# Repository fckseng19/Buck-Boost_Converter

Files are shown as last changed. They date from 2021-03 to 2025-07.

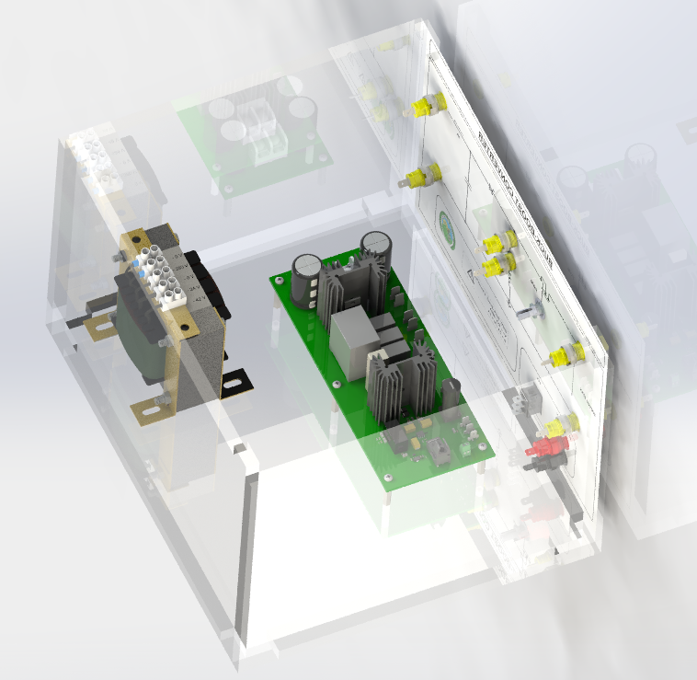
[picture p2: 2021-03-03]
Buck-Boost Module/atras_buck_boost.PNG

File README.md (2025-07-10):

# Buck-Boost_Converter
Aquí se encuentran todas las simulaciones utilizadas en el diseño del convertidor Buck-Boost como también los archivos de las PCB,Gerber, Drill, Assambly, schematics, BOM, etc

Modulos:





PCB:




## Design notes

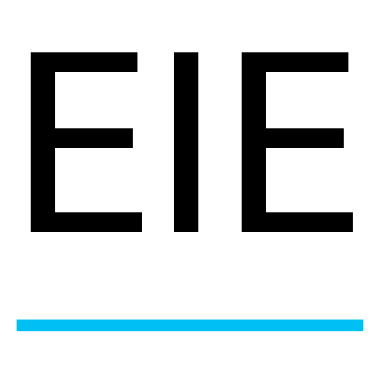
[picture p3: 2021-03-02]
Buck-Boost/PCB/Image/eie.png

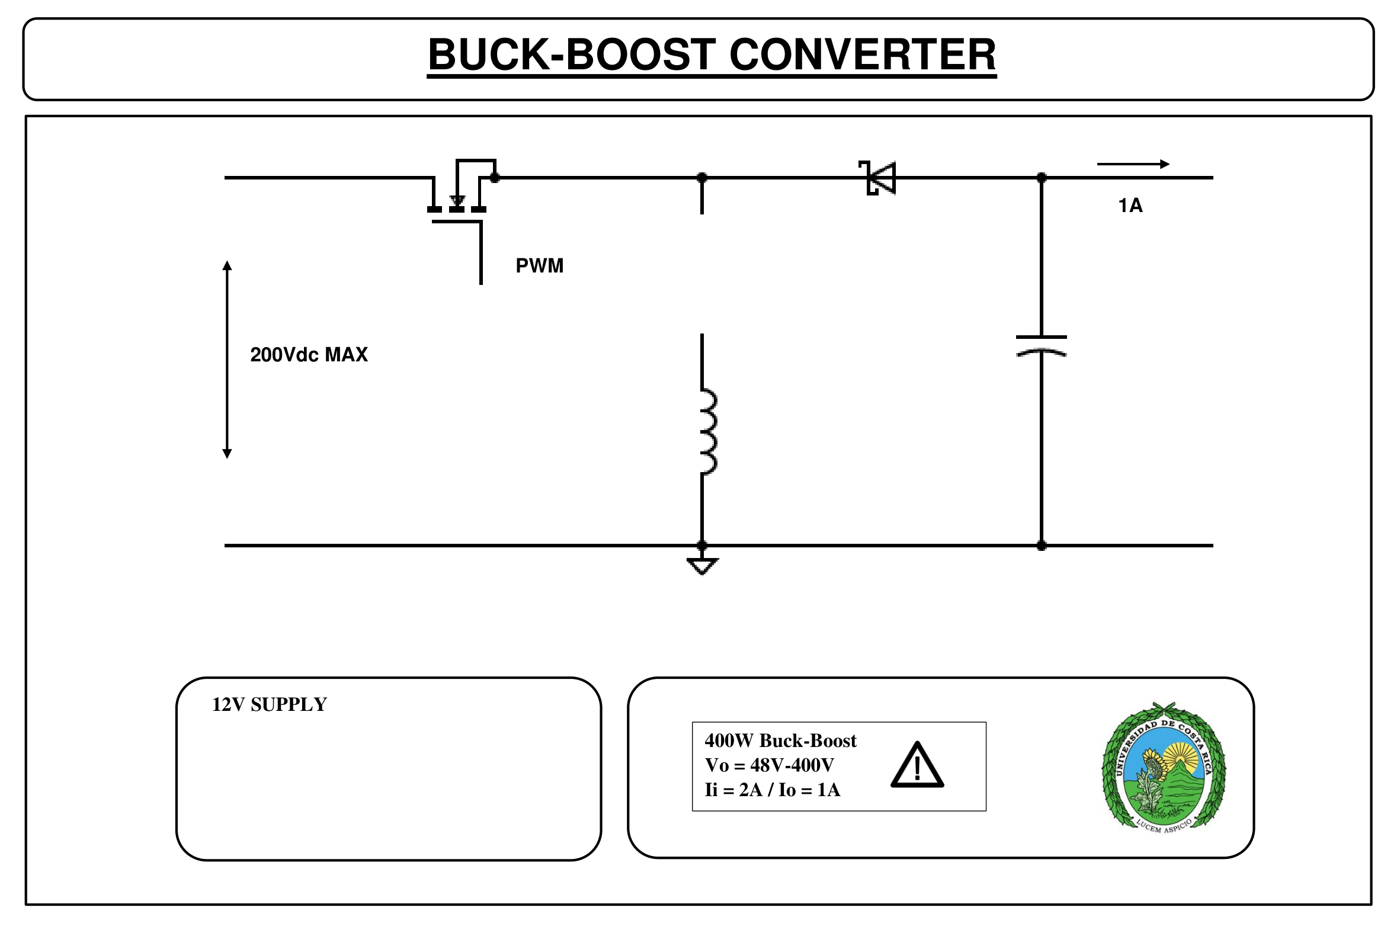
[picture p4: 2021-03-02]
Buck-Boost/Módulo/PANEL_FRONTAL_BUCKBOOST.png

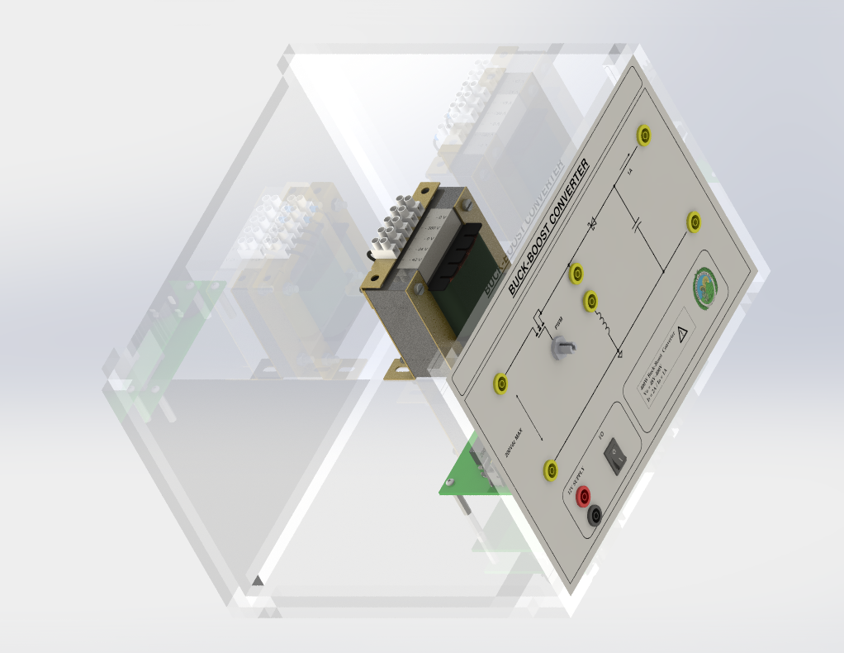
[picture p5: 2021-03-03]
Buck-Boost Module/lateral_buckboot.PNG

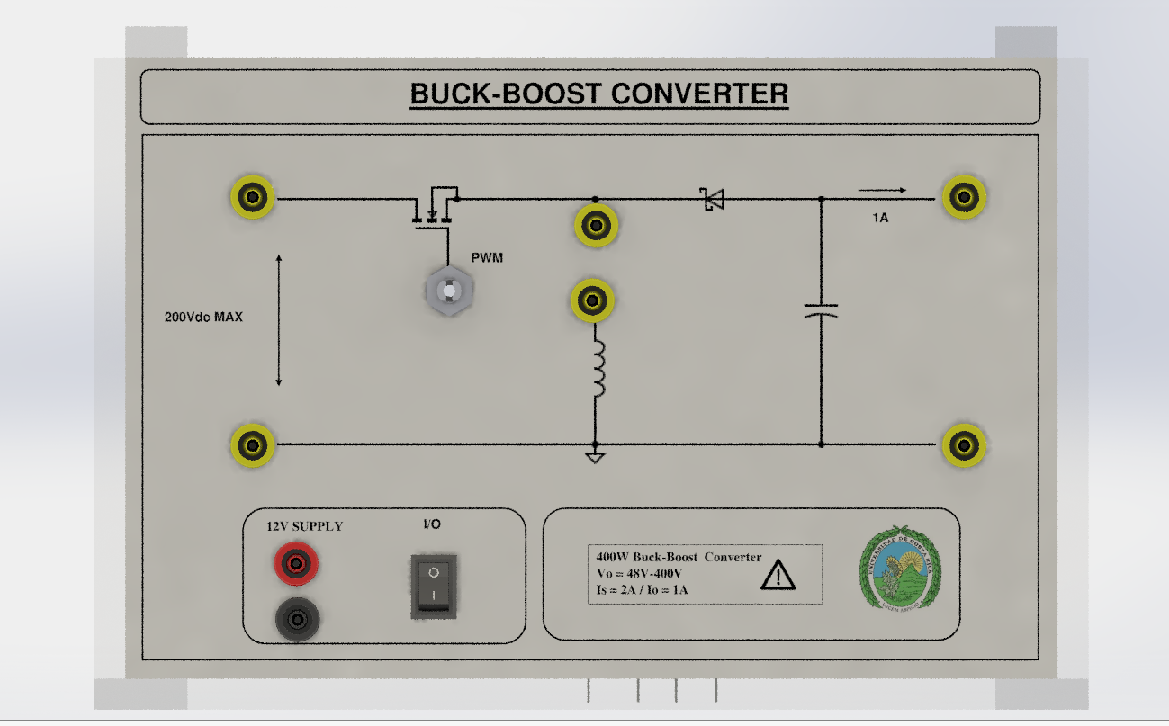
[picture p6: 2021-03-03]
Buck-Boost Module/frontal_buck_boost.PNG

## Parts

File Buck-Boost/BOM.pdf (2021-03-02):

# Bill of Materials

Project Title: Bill of Materials for Project [Buck-Boost-Converter.PrjPcb] (No PCB Document Selected)

### Project File Name: Buck-Boost-Converter.PrjPcb

### Assembly Variant: None

Part Number | Description | Designator | Manufacture | Manufacture Part Number | Supplier | Supplier Part Number | Supplier Unit Price | Quantity
R15P21503D | 2W DC/DC-Converter 'ECONOLINE' SIP7 6.4kV unreg; V. In: 15; V. Out: +15/-03; mA. Out: +93/-185 | U2 | Recom | R15P21503D | Digi-Key | 945-3070-5-ND | $8,47 | 1
UCC5390ECD | 10-A/10-A, 3-k/5-kVRMS single-channel isolated gate driver with 12-V UVLO, bipolar supply 8-SOIC -40 to 125 | U3 | Texas Instruments | UCC5390ECD | Digi-Key | 296-48101-ND | $2,81 | 1
6399BG | AAVID THERMALLOY 6399BG Heat Sink, TO-220/218, TO-220, 3.3 C/W, 50 mm, 41.91 mm, 25.4 mm | H1, H2 | Aavid Thermalloy | 6399BG | Digi-Key | HS528-ND | $6,20 | 2
8PCV-02-006 | Barrier Terminal Blocks VERTICAL RAISED 2P | J4 | TE Connectivity | 8PCV-02-006 | Digi-Key | A98460-ND | $1,84 | 1
SMAJ5.0A | BOURNS - SMAJ5.0A - TVS Diode, SMAJ Series, Unidirectional, 5 V, 9.2 V, DO-214AC (SMA), 2 Pins | D5 | Bourns | SMAJ5.0A | Digi-Key | SMAJ5.0ABCT-ND | $0,49 | 1
CT2238-0 | Cable Assembly 4MM Safety Jack, Panel W/.25 Fast on Terminal Black | Banana connector1, Banana connector2, Banana connector5, Banana connector6 | Cal Test Electronics | CT2238-0 | Digi-Key | BKCT2238-0-ND | $2,00 | 4
CT2238-2 | Cable Assembly 4MM Safety Jack, Panel W/.25 Fast on Terminal Red | Banana connector3, Banana connector4, Banana connector7, Banana connector8, Banana connector9, Banana connector10 | Cal Test Electronics | CT2238-0 | Digi-Key | BKCT2238-0-ND | $2,00 | 6
475MXH100MEFCSN22X35 | Cap Aluminum Lytic 100uF 475V 20% (22 X 35mm) Snap-In 10mm 880mA 2000h 105C | C4, C5 | Rubycon | 475MXH100MEFCSN22X35 | Digi-Key | 1189-3424-ND | $3,65 | 2
C0603C104M5RACTUCAP CER 0.1UF 50V X7R 0603 | | C11, C16, C17, C27 | KEMET | C0603C104M5RACTU | Digi-Key | 399-7845-1-ND | $0,10 | 4
UMK212B7224KG-T | CAP CER 0.22UF 50V X7R 0805 | C21, C24 | Taiyo Yuden | UMK212B7224KG-T | Digi-Key | 587-1287-1-ND | $0,14 | 2
CC0603KRX7R7BB105CAP CER 1UF 16V X7R 0603 | | C13 | Yageo | CC0603KRX7R7BB105 | Digi-Key | 311-1446-1-ND | $0,15 | 1
TMK107B7105KA-TCAP CER 1UF 25V X7R 0603 | | C12 | Taiyo Yuden | TMK107B7105KA-T | Digi-Key | 587-2984-1-ND | $0,11 | 1
UMK107AB7105KA-TCAP CER 1UF 50V X7R 0603 | | C8, C14 | Taiyo Yuden | UMK107AB7105KA-T | Digi-Key | 587-3247-1-ND | $0,28 | 2
UMK316AB7475KL-TCAP CER 4.7UF 50V X7R 1206 | | C10, C26 | Taiyo Yuden | CEUMK316AB7475KL-T | Digi-Key | 587-2994-1-ND | $0,33 | 2
TMK316AB7106KL-TCAP CER 10UF 25V X7R 1206 | | C9, C15 | Taiyo Yuden | TMK316AB7106KL-T | Digi-Key | 587-3486-1-ND | $0,33 | 2
UMK325C7106MM-TCAP CER 10UF 50V X7S 1210 | | C20, C23 | Taiyo Yuden | CEUMK325C7106MM-T | Digi-Key | 587-1818-1-ND | $0,61 | 2
06035A101FAT2A | CAP CER 100PF 50V C0G/NP0 0603 | C25 | Kyocera AVX | 06035A101FAT2A/4K | Digi-Key | 478-6202-1-ND | $0,20 | 1
T491D106K050AT | CAP TANT 10UF 10% 50V 2917 | C18, C19, C22 | KEMET | T491D106K050AT | Digi-Key | 399-8361-1-ND | $2,02 | 3
HFBR-4505Z | Conn POF Adapter Simplex F/F ST Panel Mount | PWM-INPUT1 | Broadcom Avago | HFBR-4505Z | Digi-Key | 516-1748-ND | $1,88 | 1
1217133-1 | CONN QC TAB 0.187 SOLDER | J10, J11, J12 | TE Connectivity | 1217133-1 | Digi-Key | A100449CT-ND | $0,14 | 3
195J10 | Fixed Inductors CHOKE | L1 | Hammond Manufacturing | 195J10 | Digi-Key | HM2135-ND | $68,56 | 1
3101,004 | Fuse Holder, 400 V, 16 A, TH | F1 | Schurter | 3101,004 | Digi-Key | 486-1159-ND | $4,02 | 1
5SF 10-R | Fuse, 10 A, 250 VAC, N/A | F2 | Bel | 5SF10-R | Digi-Key | 507-1235-ND | $0,24 | 1
RA111C1021-136 | Illuminated Rocker Switches 16A 125VAC 4.8mm Tab Off-On | Rocker Switch 2PST | E-Switch | RA111C1021-136 | Digi-Key | RA111C1021-136-ND | $1,18 | 1
R75PI32204030J | KEMET R75PI32204030J Film Capacitor, AEC-Q200 R75 Series, 0.22 F, 5%, PP (Polypropylene), 630 V | C1, C3, C6, C7 | KEMET | R75PI32204030J | Digi-Key | 399-12761-ND | $0,95 | 4
C4AQLBU5250A12K | KEMET C4AQLBU5250A12K. CAP FILM 25UF 10% 500VDC RADIAL | C2 | KEMET | C4AQLBU5250A12K | Digi-Key | 399-16989-ND | $7,00 | 1
150060GS75000 | LED GREEN CLEAR 0603 SMD | D3, D4 | Wurth Electronics | 150060GS75000 | Digi-Key | 732-4971-1-ND | $0,14 | 2
CMP-0003646-1 | MACHINE SCREW PAN PHILLIPS M3 5mm | H7, H8, H9, H10, H13, H14 | Building Fasteners | MPMS 003 0005 PH | Digi-Key | H742-ND | $0.63 | 6
PMEG6010CEJ,115 | PMEG6010CEH; PMEG6010CEJ - 1 A very low VF MEGA Schottky barrier rectifiers | D2 | Nexperia | PMEG6010CEJ,115 | Digi-Key | 1727-3882-1-ND | $0,35 | 1
62409-1 | Quick Disconnect Terminal M 15.8mm 7.5mm Tin Over Copper Automotive Bag | J1, J2, J3, J5, J6, J7, J8 | TE Connectivity | 62409-1 | Digi-Key | A24742-ND | $0,19 | 7
CRCW12062R70FKEAHP | RES SMD 2.7 OHM 1% 3/4W 1206 | R5 | Vishay Dale | CRCW12062R70FKEAHP | Digi-Key | 541-2.70UCT-ND | $0,43 | 1
RC0603FR-0710KL | RES SMD 10K OHM 1% 1/10W 0603 | R2, R3 | Mepco Philips | RC0603FR-0710KL | Digi-Key | 311-10.0KHRCT-ND | $0,10 | 2
RC0603FR-0720KL | RES SMD 20K OHM 1% 1/10W 0603 | R6 | Yageo | RC0603FR-0720KL | Digi-Key | 311-20.0KHRCT-ND | $0,10 | 1
CRCW0603100RFKEAC | RES SMD 100 OHM 1% 1/10W 0603 | R4 | Vishay | CRCW0603100RFKEAC | Digi-Key | 541-3951-1-ND | $0,10 | 1
HFBR-2531Z | RX Optical Fiber 5MBd 6-Pin | Rx1 | Broadcom Avago | HFBR-2531Z | Digi-Key | 516-2067-ND | $12,98 | 1
C3M0045065K | Sic MOSFET 650V | Q1 | WolfSpeed | C3M0045065K | DigiKey | 1697-C3M0045065K-ND | $10,25 | 1
C6D06065A | Sic Schottky Diode, VRRM = 650V. IF= 6A | D1 | Cree Wolfspeed | C6D06065A | Digi-Key | 1697-C6D06065A-ND | $1,80 | 1
SP900S-0.009-AC-58Silcon Thermal Pad | | SIL1, SIL2 | Bergquist | SP900S-0.009-AC-58 | Digi-Key | BER183-ND | | 2
CMP-0003640-1 | Standoff, Hex,25mm Length, M3, Aluminum | H3, H4, H5, H6, H11, H12 | Keystone Electronics | 24438 | Digi-Key | 36-24438-ND | $0,68 | 6
282834-2 | TE CONNECTIVITY / BUCHANAN - 282834-2 -TERMINAL BLOCK, WIRE TO BRD, 2POS, 16AWG | J9 | BUCHANAN - TE CONNECTIVITY | 282834-2 | Digi-Key | A98333-ND | $1,27 | 1
5011 | Test Point, Multipurpose, Black, TH | TP5, TP13, TP22, TP23 | Keystone Electronics | 5011 | Digi-Key | 36-5011-ND | $0,40 | 4
5010 | Test Point, Multipurpose, Red, TH | TP1, TP2, TP3, TP4, TP6, TP7, TP8, TP9, TP10, TP11, TP15, TP16, TP17, TP19, TP20, TP21 | Keystone Electronics | 5010 | Digi-Key | 36-5010-ND | $0,40 | 16
SMAJ16A | TVS DIODE 16VWM 26VC DO214AC | D6 | Bourns | SMAJ16A | Digi-Key | SMAJ16ABCT-ND | $0,49 | 1
L78L05ACUTR | Voltage regulator; linear, fixed; 5V; 0.1A; SOT89; SMD; 0÷125°C | U1 | STMicroelectronics | L78L05ACUTR | Digi-Key | 497-1183-1-ND | $0,53 | 1
SQMW747RJ | Wirewound Resistors 47 Ohms 7W 300PPM | R1 | TE Connectivity | 1-1623789-5 | Digi-Key | A102485-ND | $0,69 | 1
Total | $146,60 107

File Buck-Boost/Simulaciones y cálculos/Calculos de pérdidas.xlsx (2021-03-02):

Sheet: Sheet1
Cálculo de pérdidas del MOSFET
Ingrese los parámetros de la hoja de datos acá
MOSFET |  |  | Perdidas del Transistor |  |  | Diseño del disipador MOSFET
Parámetros estaticos |  |  | Símbolo | Valor | Unidad | Símbolo | Valor | Unidad
Símbolo | Valor | Unidad | Pcond | 10.51 | W | P_sin_Hs | 3.125 | W
R_DS(on) | 0.28 | V | Psw | 6.30 | W | Rsa | 5.1 | C/W
id | 7.5 | A | Ptot | 16.8 | W
D | 0.667 | %
Parámetros de conmutación
Eon | 5.7e-05 | J
Eoff | 6e-06 | J | Perdidas del Diodo |  |  | Diseño del disipador Diodo
Etot | 6.3e-05 | J | Símbolo | Valor | Unidad | Símbolo | Valor | Unidad
fsw | 100000 | Hz | PD | 12.8 | W | P_sin_Hs | 3.75 | W
Parámetros Térmicos |  |  |  |  |  | Rsa | 9.7 | C/W
Tjmax | 150 | C
Ta | 25 | C
Rja | 40 | C/W
Rjc | 2.3 | C/W
Diodo
Parámetros estaticos
Símbolo | Valor | Unidad
VF | 1.6 | V
IF | 24 | A
IR | 0.00012 | A
Parámetros Térmicos
Tjmax | 175 | C
Ta | 25 | C
Rja | 40 | C/W
Rjc | 2.05 | C/W
Cálculo de pérdidas del Diodo
Ingrese los parámetros de la hoja de datos acá
MOSFET |  |  | Perdidas del Diodo |  |  | Diseño del disipador Diodo
Parámetros estaticos |  |  | Símbolo | Valor | Unidad | Símbolo | Valor | Unidad
Símbolo | Valor | Unidad | Pcond | 6.86 | W | P_sin_Hs | 3.125 | W
R_DS(on) | 0.28 | V | Psw | 0.32 | W | Rsa | 15.1 | C/W
id | 7 | A | Ptot | 7.2 | W
D | 0.5 | %
Parámetros de conmutación
Eon | 5.7e-05 | J |  |  | Si Ptot es mayor a P_sin_Hs, entonces ocupa disipador
Eoff | 6e-06 | J
Etot | 6.3e-05 | J
fsw | 5000 | Hz
Parámetros Térmicos
Tjmax | 150 | C
Ta | 25 | C
Rja | 40 | C/W
Rjc | 2.3 | C/W

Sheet: Sheet2
Buck-Boost
Componentes | Tensión V | Corriente A | Potencia W | Encapsulado | Modelo | Precio
Inductor(10mH) |  | 10A |  |  | HM2135-ND | 68.56
MOSFET | 900V | 11A | 54W | TO-247-3 | C3M0280090D | 3.25
Diodo | 650V | 12A | 32W | TO-220-2 | C6D06065A | 1.18
Capacitor
Heatsink Diode |  |  | 9.74c/w | TO-220 | HSE-B20250-045H | 2.14
Heatsink MOSFET |  |  | 5.5 c/w Air | TO-247 | MTN-264-27 |  | este tiene para dos, podría usar solo este para ambos

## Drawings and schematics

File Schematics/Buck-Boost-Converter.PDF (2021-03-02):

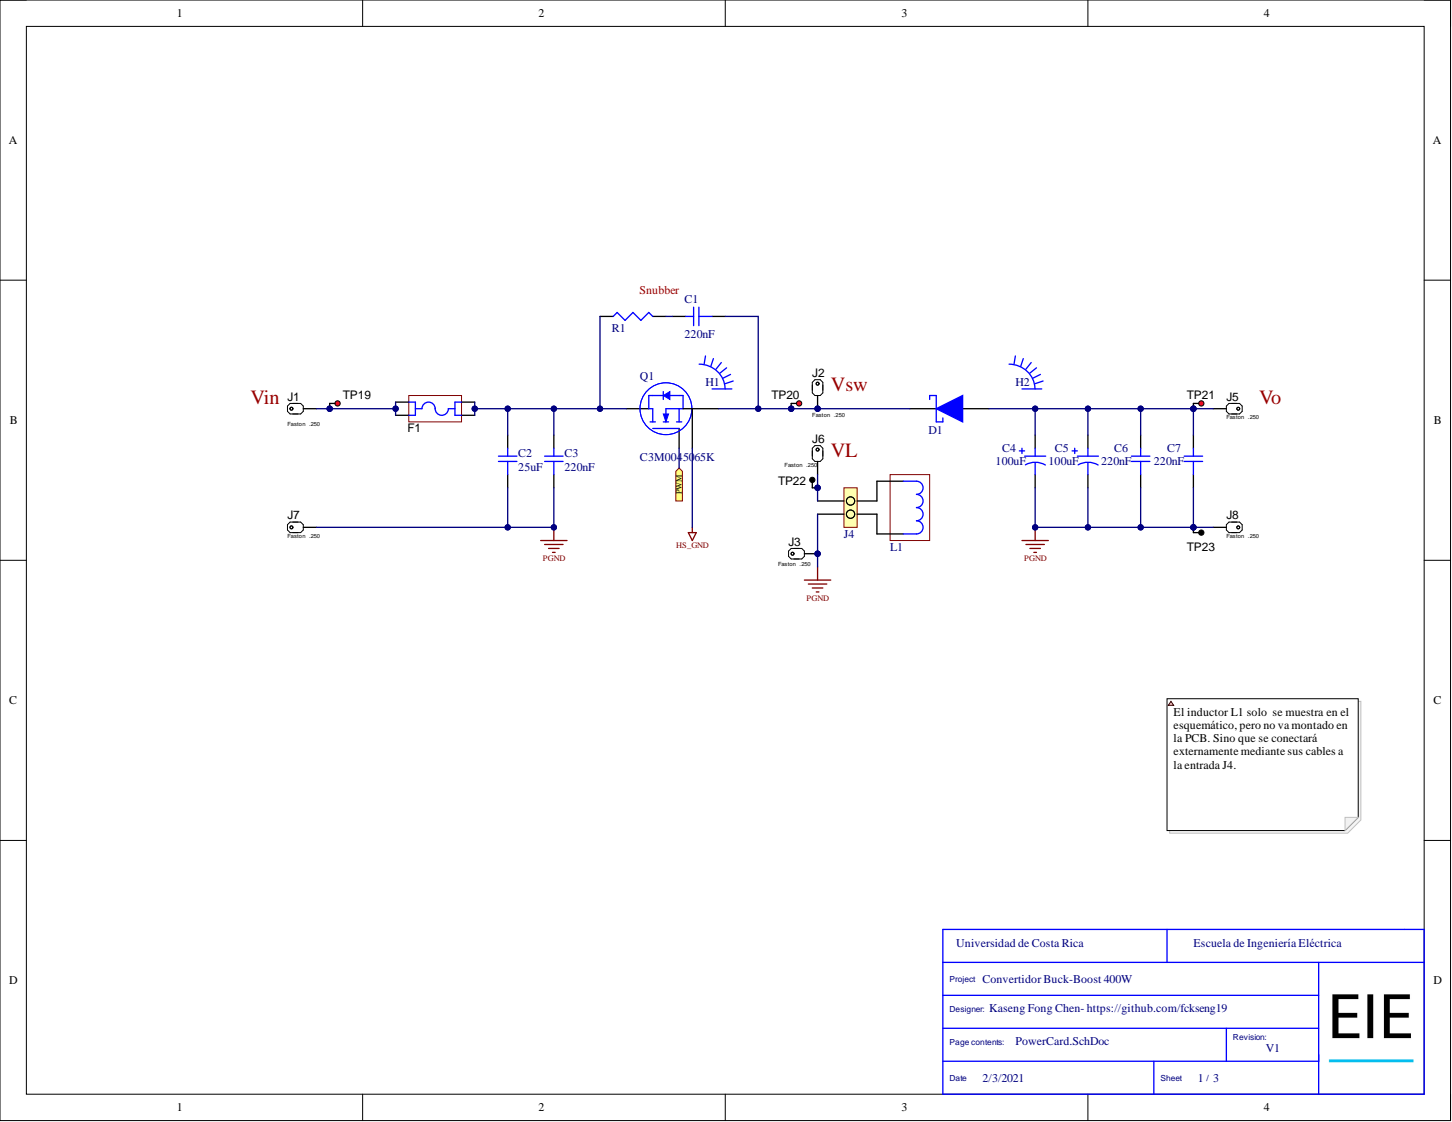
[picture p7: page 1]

U n i vers i dad de Co s ta Rica | E scuela de In gen ier ía E l éctrica

P r o j e c t Co n vert i d or Buck-Bo o s t 4 0 0 W

P a g e c o n t e n ts : Po werCard.Sch D o c | R e v i s i o n :V

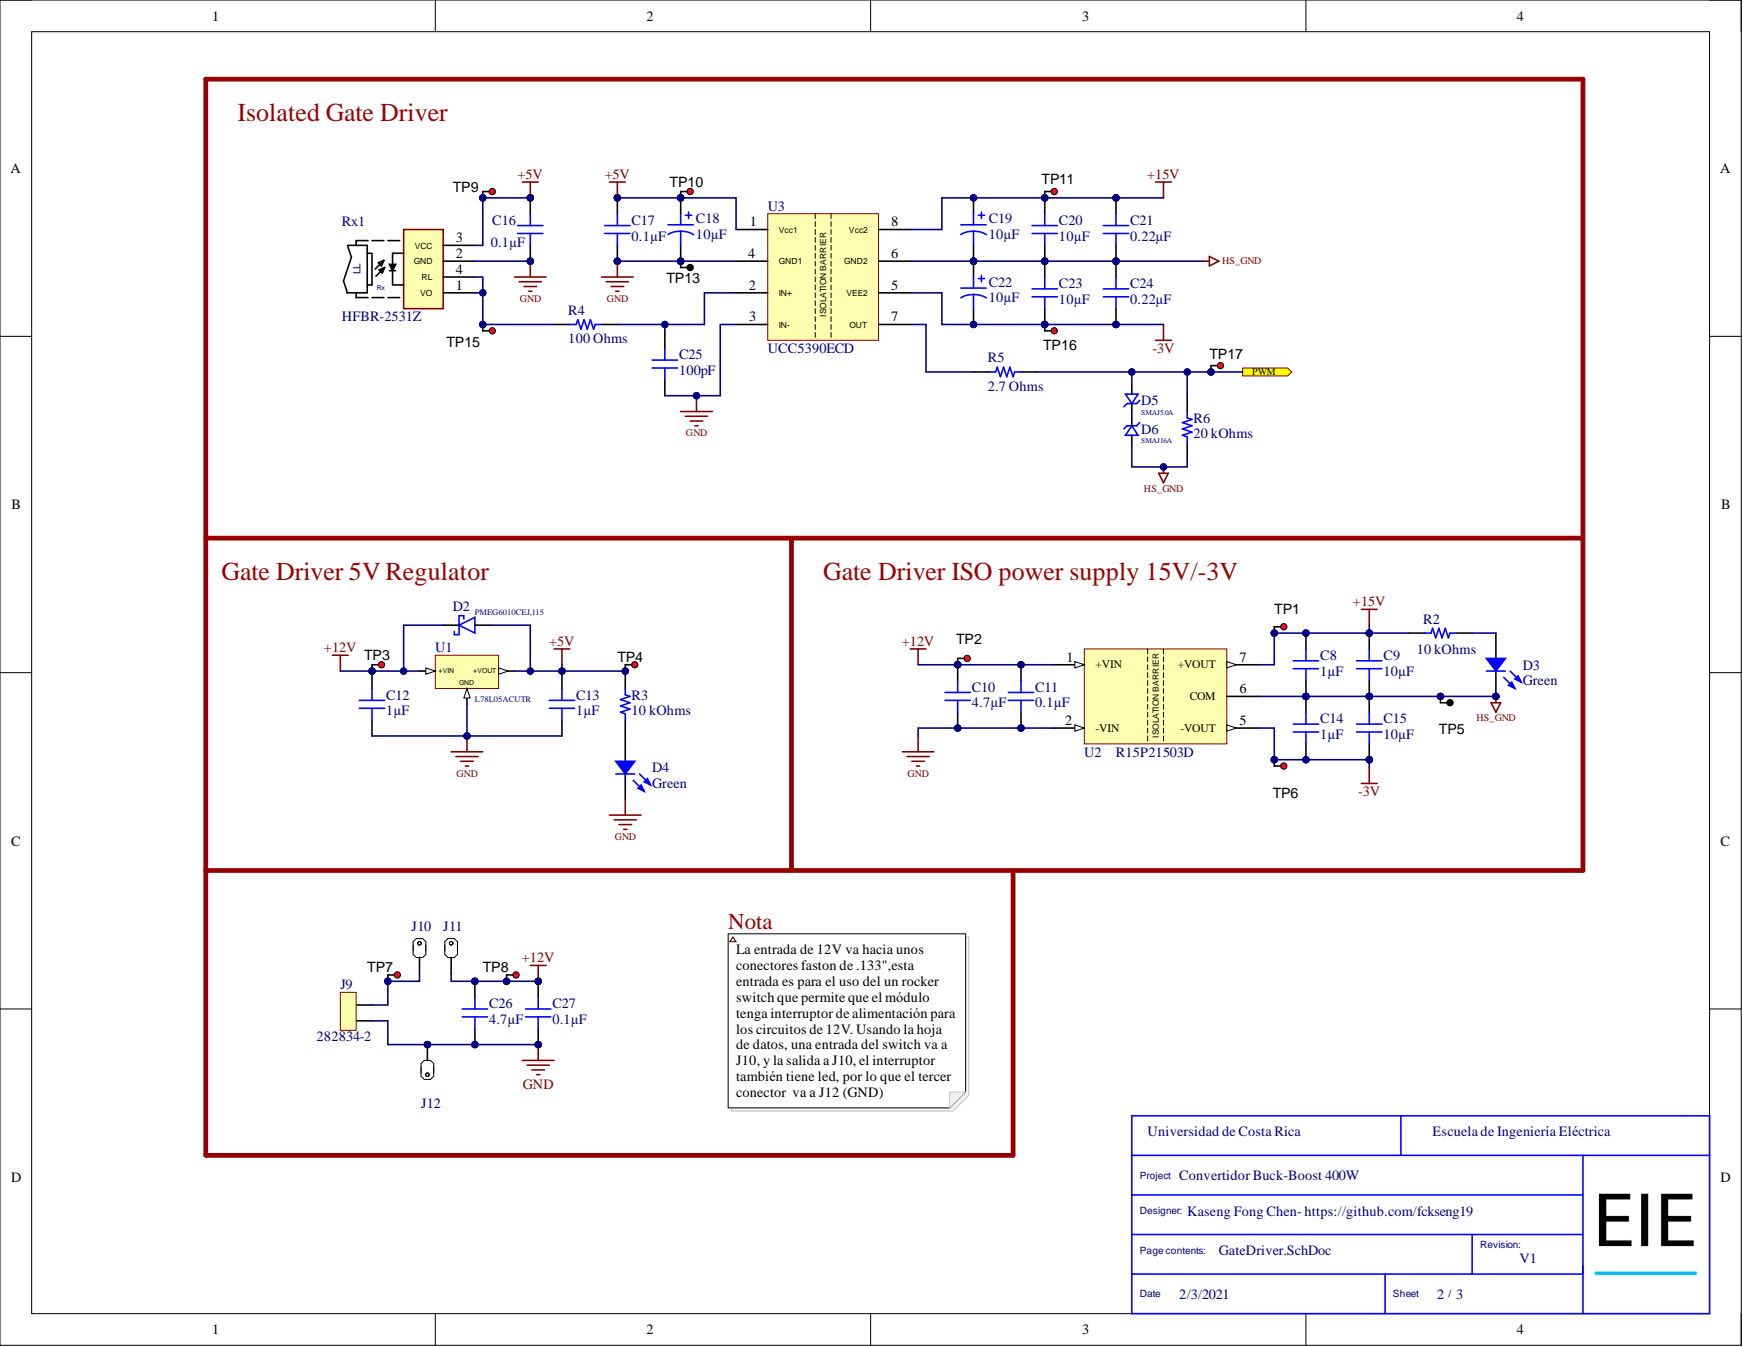
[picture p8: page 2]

C14
1µF

La entrada de 12V va hacia unos
conectoresfaston de .133",esta
entrada es para el uso del un rocker
switch que permite que el módulo
tenga interruptor de alimentación para
los circuitos de 12V. Usando la hoja
de datos, una entrada del switch va a
J10, y la salida a J10, el interruptor
también tiene led, por lo que el tercer
conector va a J12 (GND)

Universidad de Costa Rica | Escuela de Ingeniería Eléctrica

Project Convertidor Buck-Boost 400W

Kaseng Fong Chen- https://github.com/fckseng19

GateDriver.SchDoc | Revision: V1 Page contents:

Date 2/3/2021 | Sheet 2 / 3

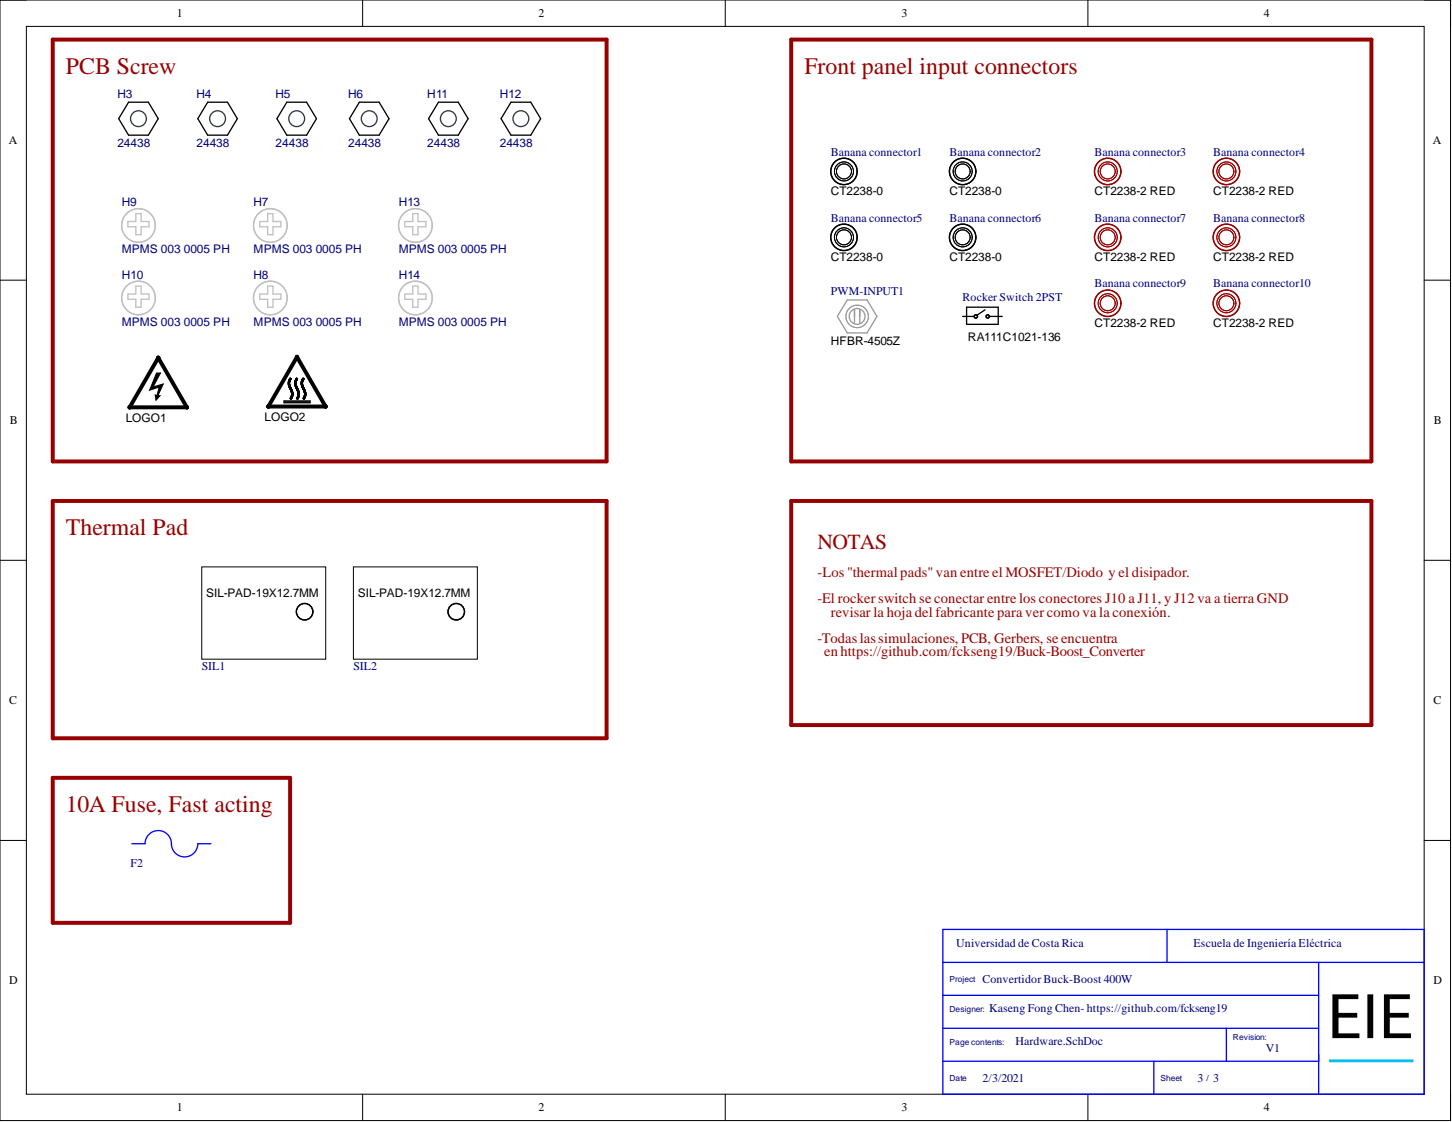
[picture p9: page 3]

Front panel input connectors

-Los "thermal pads" van entre el MOSFET/Diodo y el disipador.

-El rocker switch se conectar entre los conectores J10 a J11, y J12 va a tierra GND revisar la hoja del fabricante para ver como va la conexión.

-Todas las simulaciones, PCB, Gerbers, se encuentra en https://github.com/fckseng19/Buck-Boost_Converter

Universidad de Costa Rica | Escuela de Ingeniería Eléctrica

Project Convertidor Buck-Boost 400W

Kaseng Fong Chen- https://github.com/fckseng19

Hardware.SchDoc | Revision: V1 Page contents:

Date 2/3/2021 | Sheet 3 / 3

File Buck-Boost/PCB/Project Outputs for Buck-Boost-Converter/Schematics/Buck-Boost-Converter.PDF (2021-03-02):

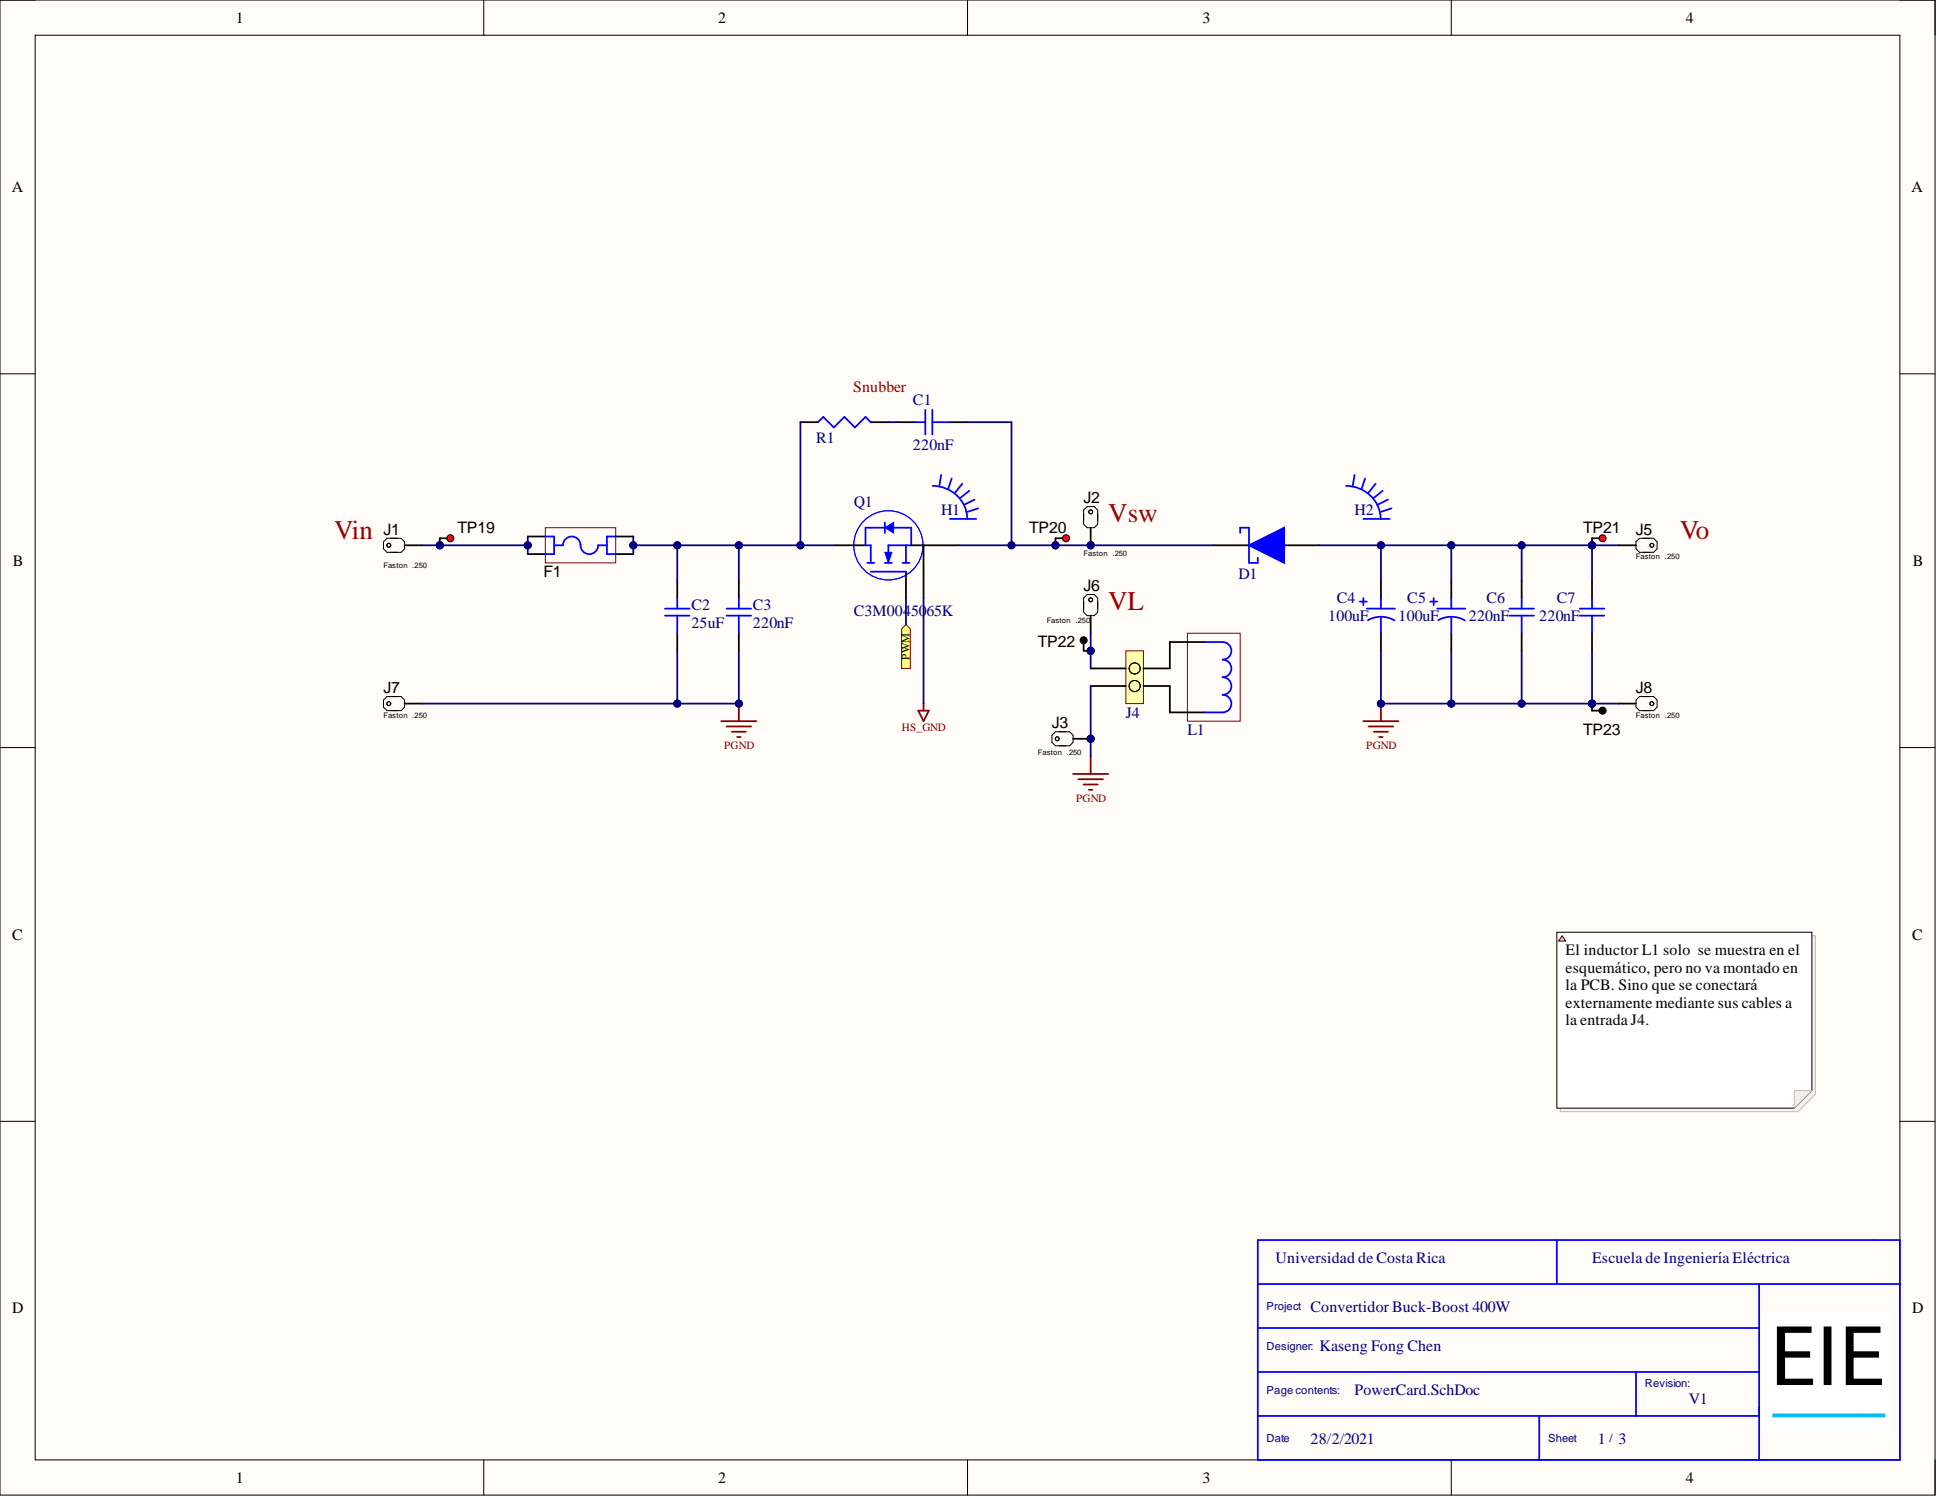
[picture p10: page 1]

U n i vers i dad de Co s ta Rica | E scuela de In gen ier ía E l éctrica

P r o j e c t Co n vert i d or Buck-Bo o s t 4 0 0 W

P a g e c o n t e n ts : Po werCard.Sch D o c | R e v i s i o n :V

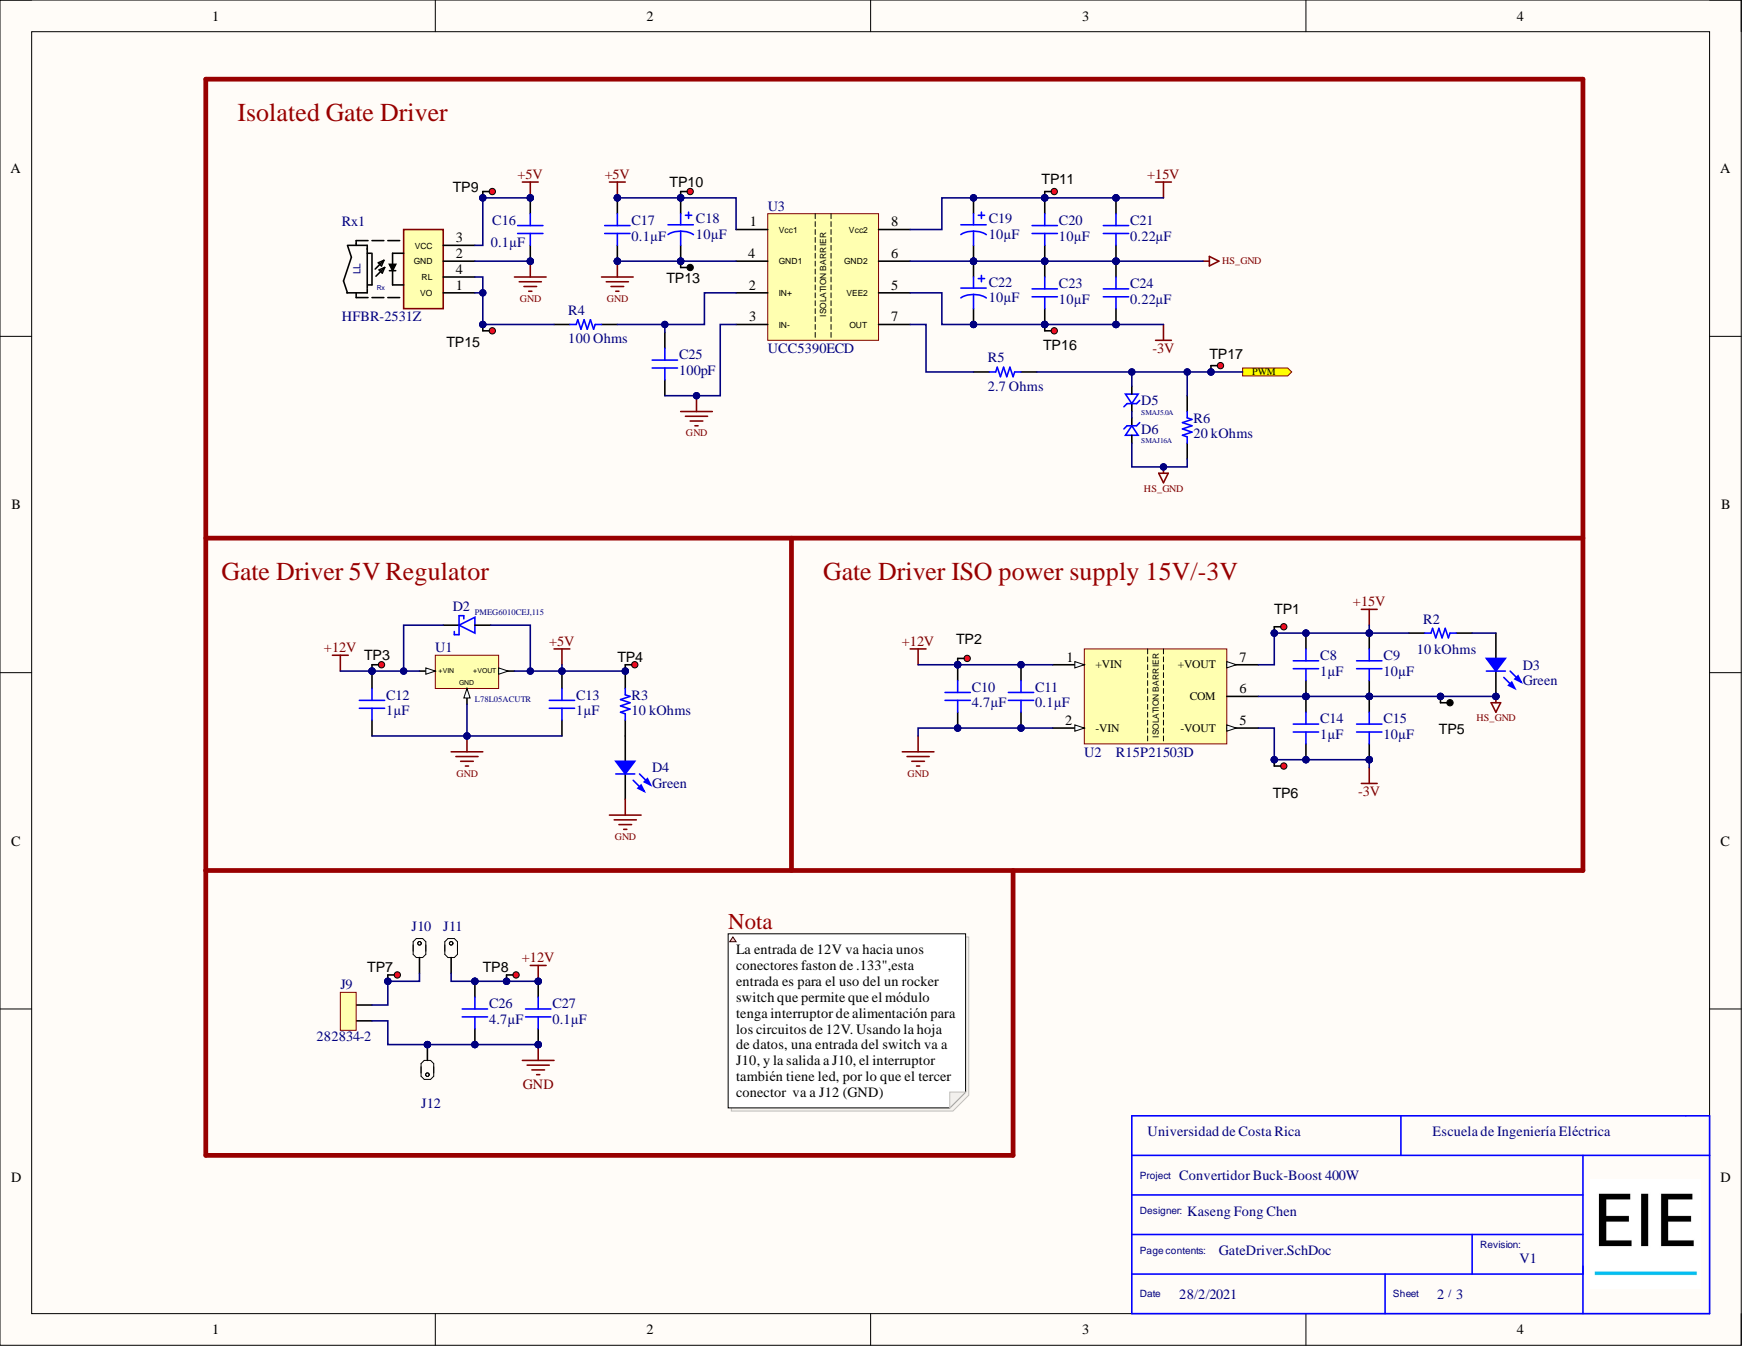
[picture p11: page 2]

C14
1µF

La entrada de 12V va hacia unos
conectoresfaston de .133",esta
entrada es para el uso del un rocker
switch que permite que el módulo
tenga interruptor de alimentación para
los circuitos de 12V. Usando la hoja
de datos, una entrada del switch va a
J10, y la salida a J10, el interruptor
también tiene led, por lo que el tercer
conector va a J12 (GND)

Universidad de Costa Rica | Escuela de Ingeniería Eléctrica

Project Convertidor Buck-Boost 400W

GateDriver.SchDoc | Revision: V1 Page contents:

Date 28/2/2021 | Sheet 2 / 3

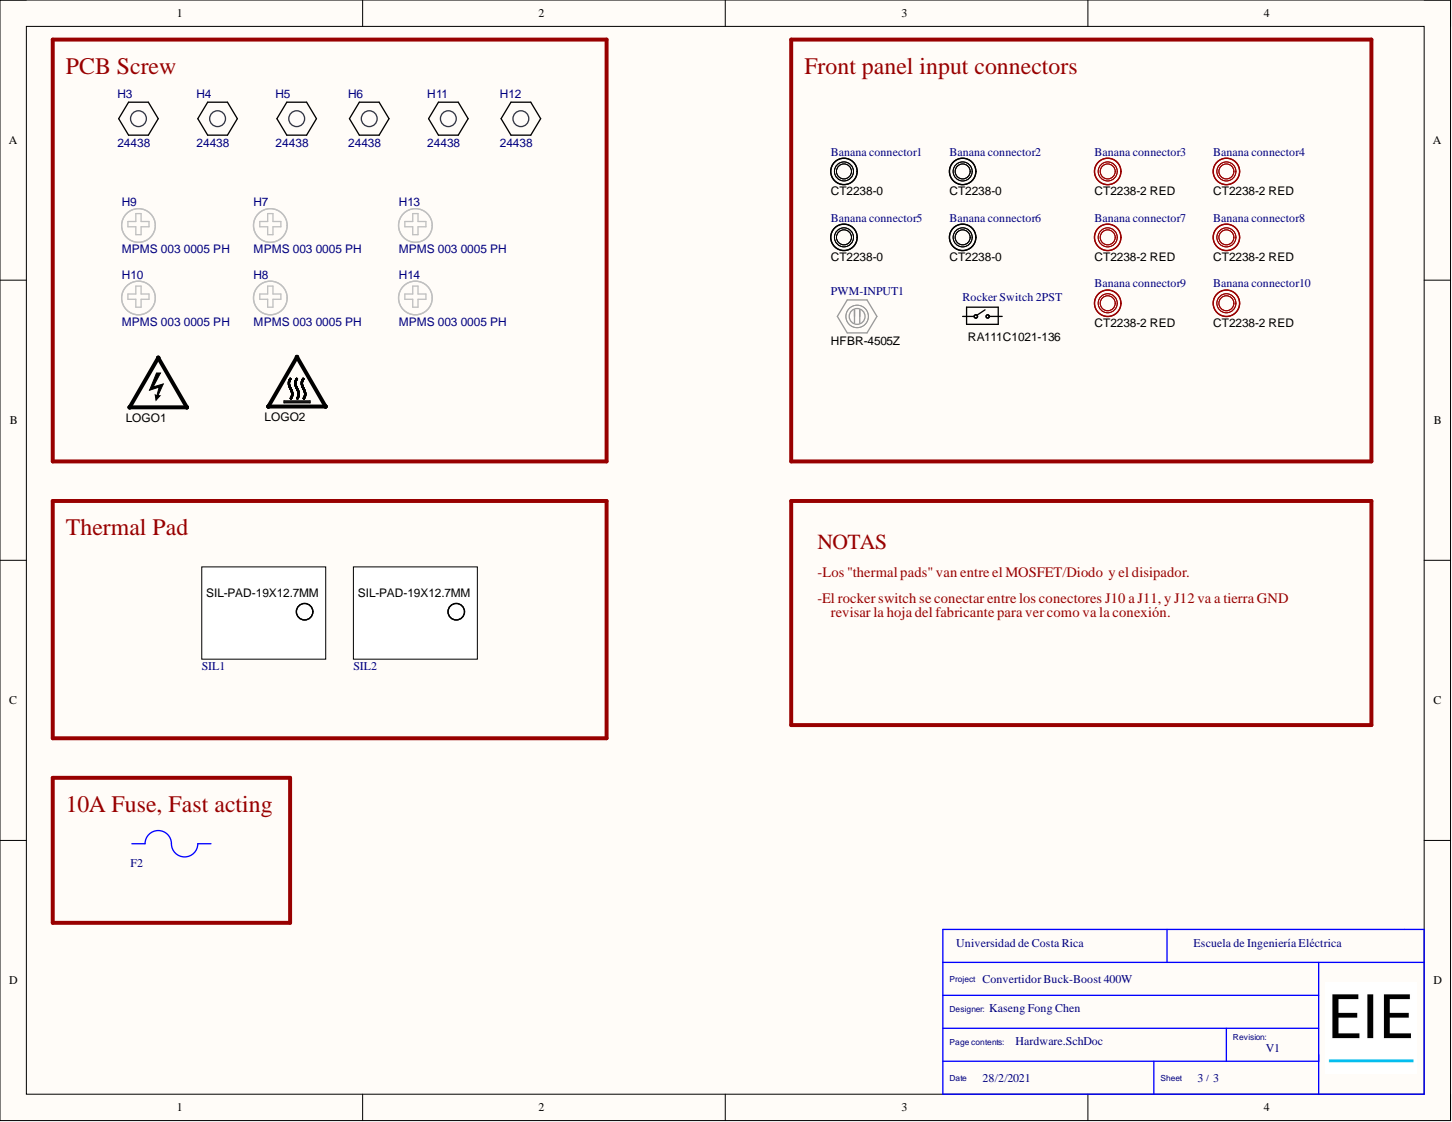
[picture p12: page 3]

Front panel input connectors

-Los "thermal pads" van entre el MOSFET/Diodo y el disipador.

-El rocker switch se conectar entre los conectores J10 a J11, y J12 va a tierra GND revisar la hoja del fabricante para ver como va la conexión.

Universidad de Costa Rica | Escuela de Ingeniería Eléctrica

Project Convertidor Buck-Boost 400W

Hardware.SchDoc | Revision: V1 Page contents:

Date 28/2/2021 | Sheet 3 / 3

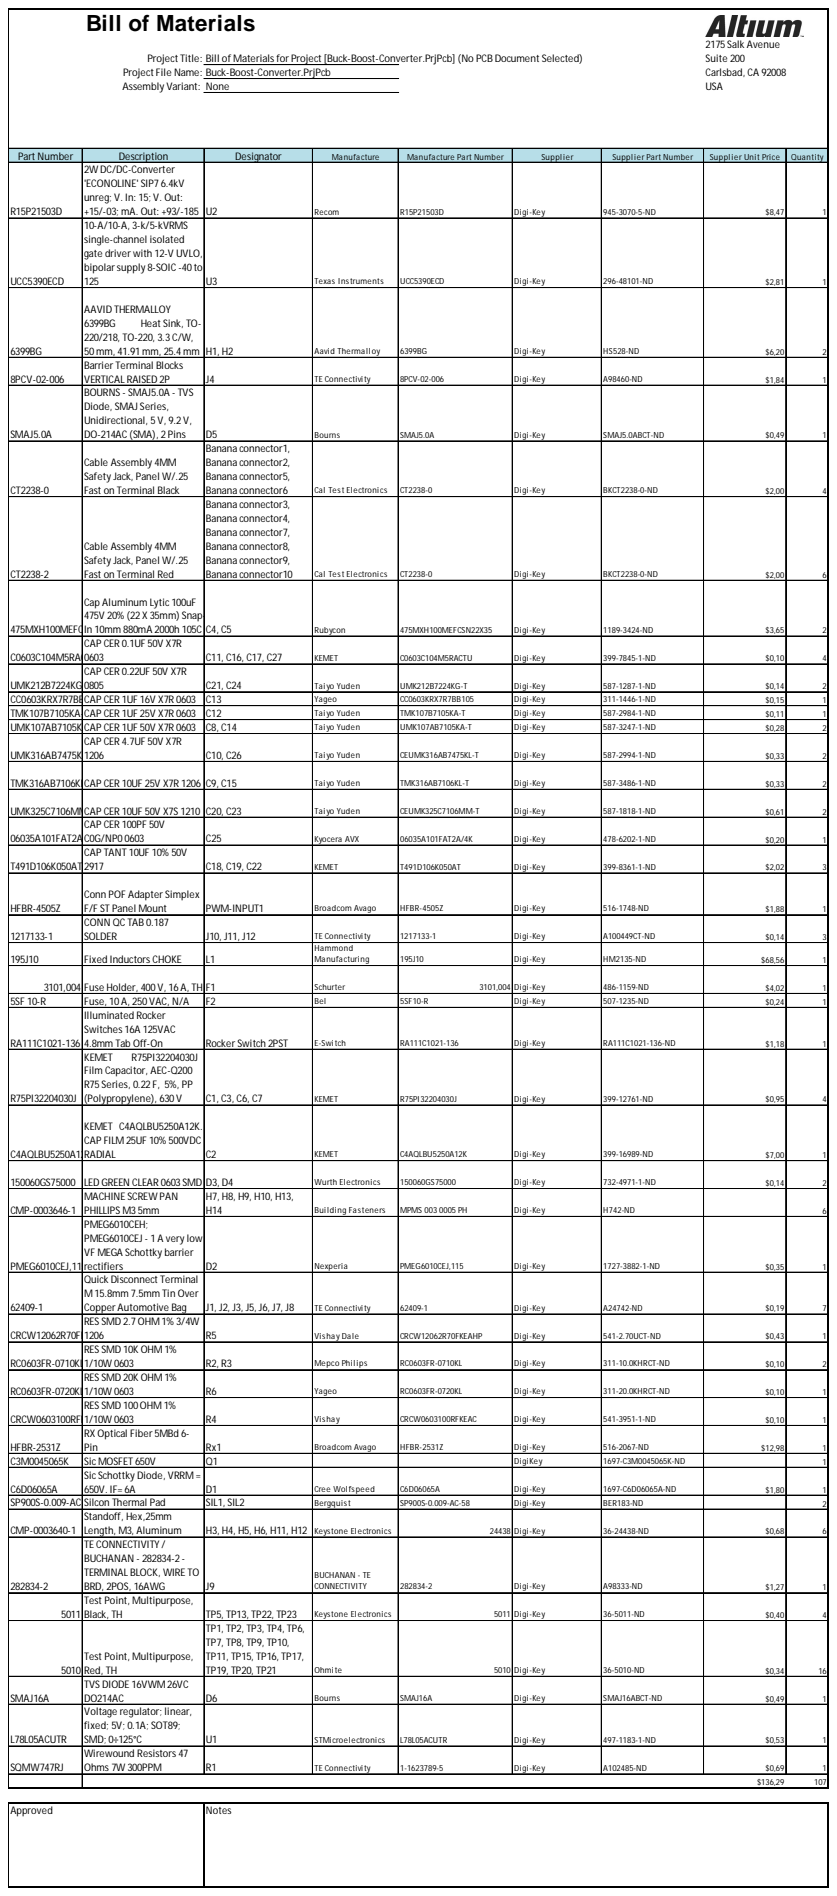
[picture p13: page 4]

Part Number | Description | Designator | Manufacture | Manufacture Part Number | Supplier | Supplier Part Number | Supplier Unit Price | Quantity
R15P21503D | 2W DC/DC-Converter 'ECONOLINE' SIP7 6.4kV unreg; V. In: 15; V. Out: +15/-03; mA. Out: +93/-185 | U2 | Recom | R15P21503D | Digi-Key | 945-3070-5-ND | $8,47 | | 1

UCC5390ECD | 10-A/10-A, 3-k/5-kVRMS single-channel isolated gate driver with 12-V UVLO, bipolarsupply 8-SOIC -40 to 125 | U3 | Texas Instruments | UCC5390ECD | Digi-Key | 296-48101-ND | $2,81 | | 1

6399BG | AAVID THERMALLOY 6399BG Heat Sink, TO-220/218, TO-220, 3.3 C/W, 50mm, 41.91mm, 25.4mm | H1, H2 | Aavid Thermalloy | 6399BG | Digi-Key | HS528-ND | $6,20 | | 2

8PCV-02-006 | Barrier Terminal Blocks VERTICAL RAISED 2P | J4 | TE Connectivity | 8PCV-02-006 | Digi-Key | A98460-ND | $1,84 | | 1

SMAJ5.0A | BOURNS - SMAJ5.0A - TVS Diode, SMAJ Series, Unidirectional, 5 V, 9.2 V, DO-214AC (SMA), 2 Pins | D5 | Bourns | SMAJ5.0A | Digi-Key | SMAJ5.0ABCT-ND | $0,49 | | 1

CT2238-0 | Cable Assembly 4MM Safety Jack, Panel W/.25 Fast on Terminal Black | Banana connector1, Banana connector2, Banana connector5, Banana connector6 | Cal Test Electronics | CT2238-0 | Digi-Key | BKCT2238-0-ND | $2,00 | | 4

CT2238-2 | Cable Assembly 4MM Safety Jack, Panel W/.25 Fast on Terminal Red | Banana connector3, Banana connector4, Banana connector7, Banana connector8, Banana connector9, Banana connector10 | Cal Test Electronics | CT2238-0 | Digi-Key | BKCT2238-0-ND | $2,00 | | 6

475MXH100MEFCSN | Cap Aluminum Lytic 100uF 475V 20% (22 X 35mm) Snap-In 10mm 880mA 2000h 105C C4, C5 | | Rubycon | 475MXH100MEFCSN22X35 | Digi-Key | 1189-3424-ND | $3,65 | | 2

C0603C104M5RACT | CAP CER 0.1UF 50V X7R 0603 | C11, C16, C17, C27 | KEMET | C0603C104M5RACTU | Digi-Key | 399-7845-1-ND | $0,10 | | 4

UMK212B7224KG | CAP CER 0.22UF 50V X7R 0805 | C21, C24 | Taiyo Yuden | UMK212B7224KG-T | Digi-Key | 587-1287-1-ND | $0,14 | | 2

CC0603KRX7R7BBCAP CER 1UF 16V X7R 0603 | | C13 | Yageo | CC0603KRX7R7BB105 | Digi-Key | 311-1446-1-ND | $0,15 | | 1
TMK107B7105KA-CA P CER 1UF 25V X7R 0603 | | C12 | Taiyo Yuden | TMK107B7105KA-T | Digi-Key | 587-2984-1-ND | $0,11 | | 1
UMK107AB7105KCAP CER 1UF 50V X7R 0603 | | C8, C14 | Taiyo Yuden | UMK107AB7105KA-T | Digi-Key | 587-3247-1-ND | $0,28 | | 2
UMK316AB7475K | CAP CER 4.7UF 50V X7R 1206 | C10, C26 | Taiyo Yuden | CEUMK316AB7475KL-T | Digi-Key | 587-2994-1-ND | $0,33 | | 2

TMK316AB7106KLCA P CER 10UF 25V X7R 1206 | | C9, C15 | Taiyo Yuden | TMK316AB7106KL-T | Digi-Key | 587-3486-1-ND | $0,33 | | 2

UMK325C7106MMCAP CER 10UF 50V X7S 1210 | | C20, C23 | Taiyo Yuden | CEUMK325C7106MM-T | Digi-Key | 587-1818-1-ND | $0,61 | | 2
06035A101FAT2A | CAP CER 100PF 50V C0G/NP0 0603 | C25 | Kyocera AVX | 06035A101FAT2A/4K | Digi-Key | 478-6202-1-ND | $0,20 | | 1

T491D106K050AT | CAP TANT 10UF 10% 50V 2917 | C18, C19, C22 | KEMET | T491D106K050AT | Digi-Key | 399-8361-1-ND | $2,02 | | 3

HFBR-4505Z | Conn POF Adapter Simplex F/F ST Panel Mount | PWM-INPUT1 | Broadcom Avago | HFBR-4505Z | Digi-Key | 516-1748-ND | $1,88 | | 1

1217133-1 | CONN QC TAB 0.187 SOLDER | J10, J11, J12 | TE Connectivity | 1217133-1 | Digi-Key | A100449CT-ND | $0,14 | | 3
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

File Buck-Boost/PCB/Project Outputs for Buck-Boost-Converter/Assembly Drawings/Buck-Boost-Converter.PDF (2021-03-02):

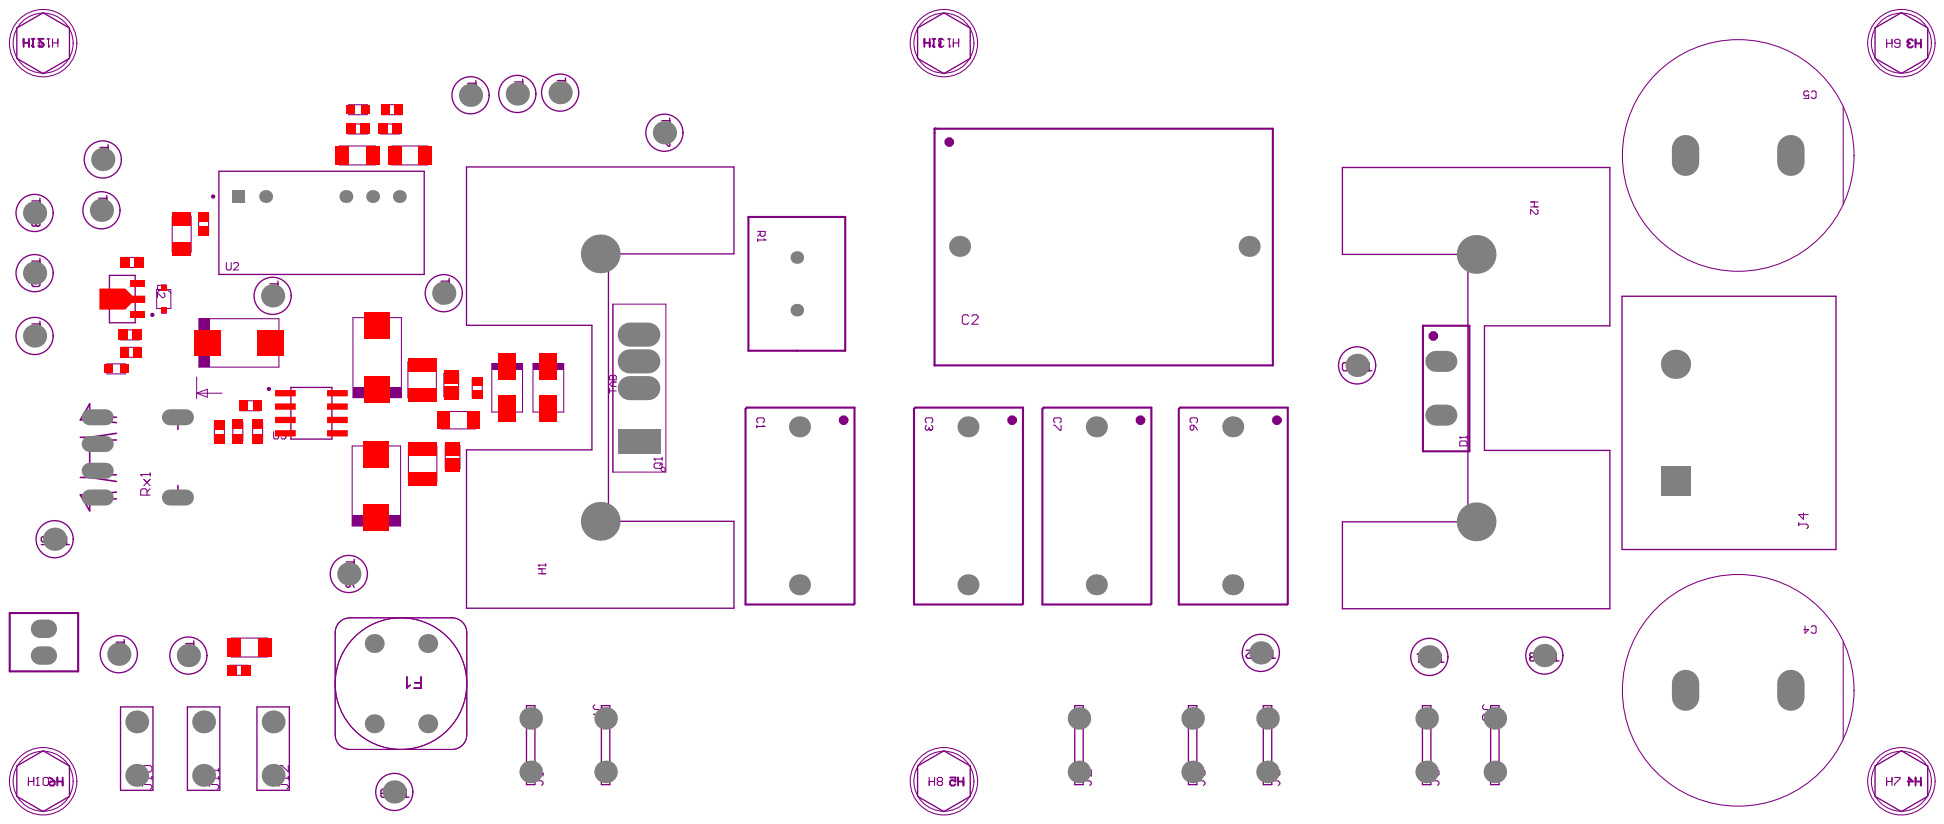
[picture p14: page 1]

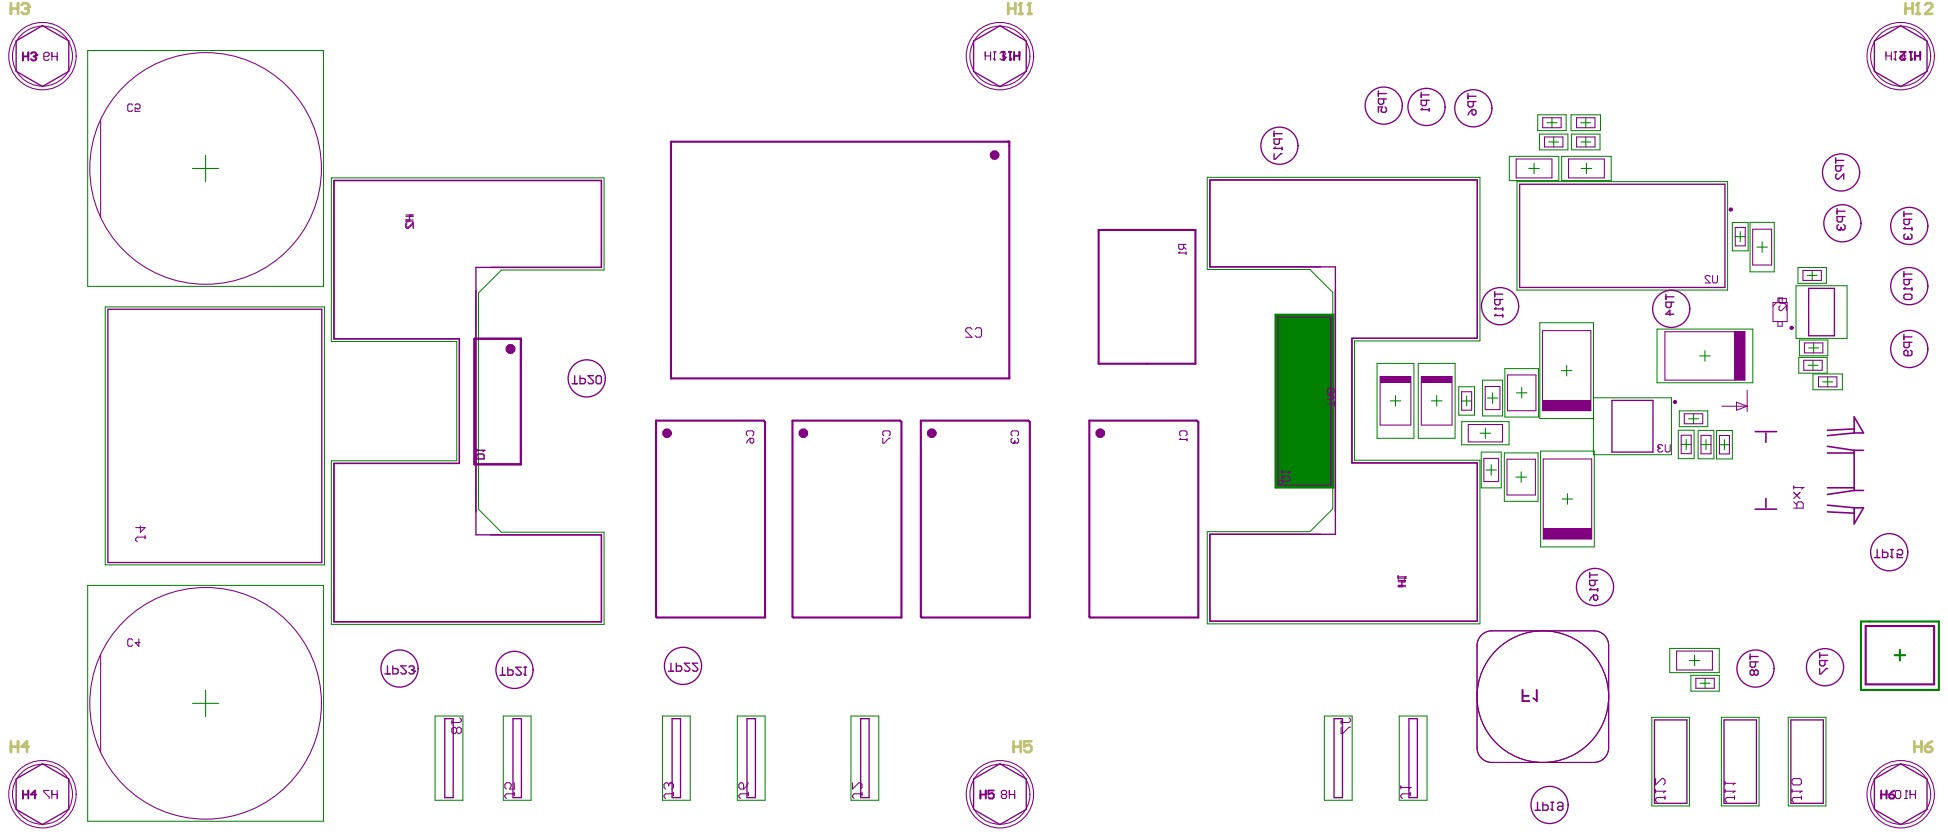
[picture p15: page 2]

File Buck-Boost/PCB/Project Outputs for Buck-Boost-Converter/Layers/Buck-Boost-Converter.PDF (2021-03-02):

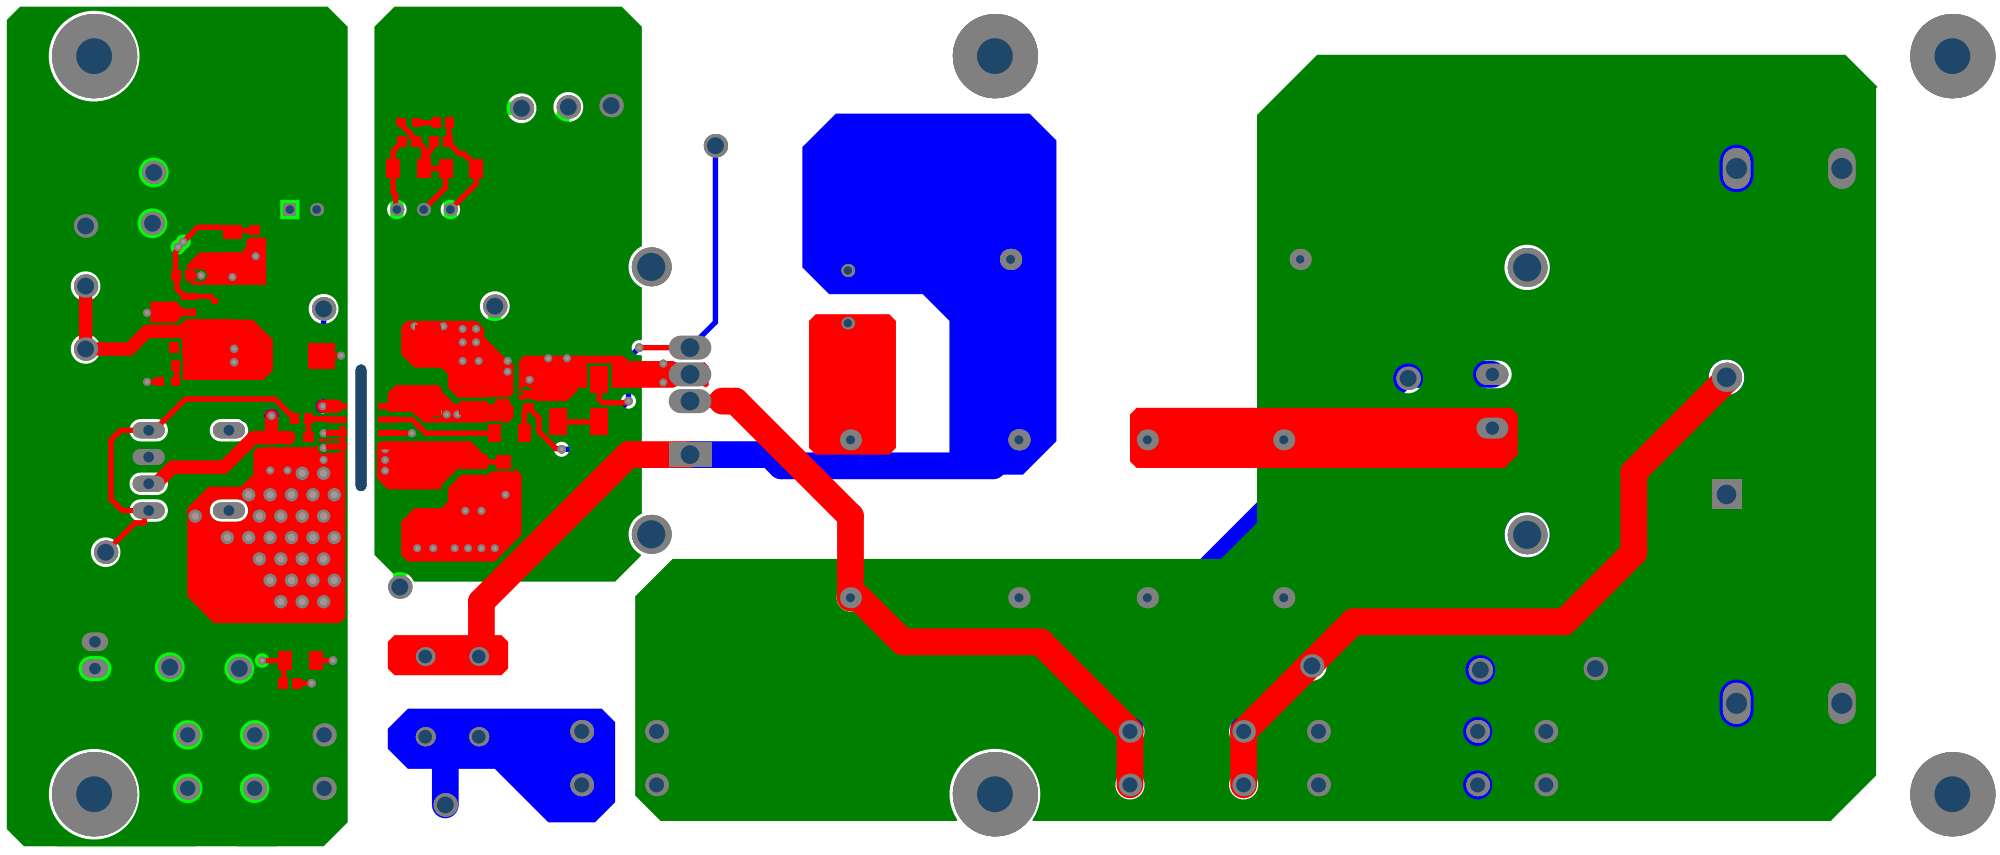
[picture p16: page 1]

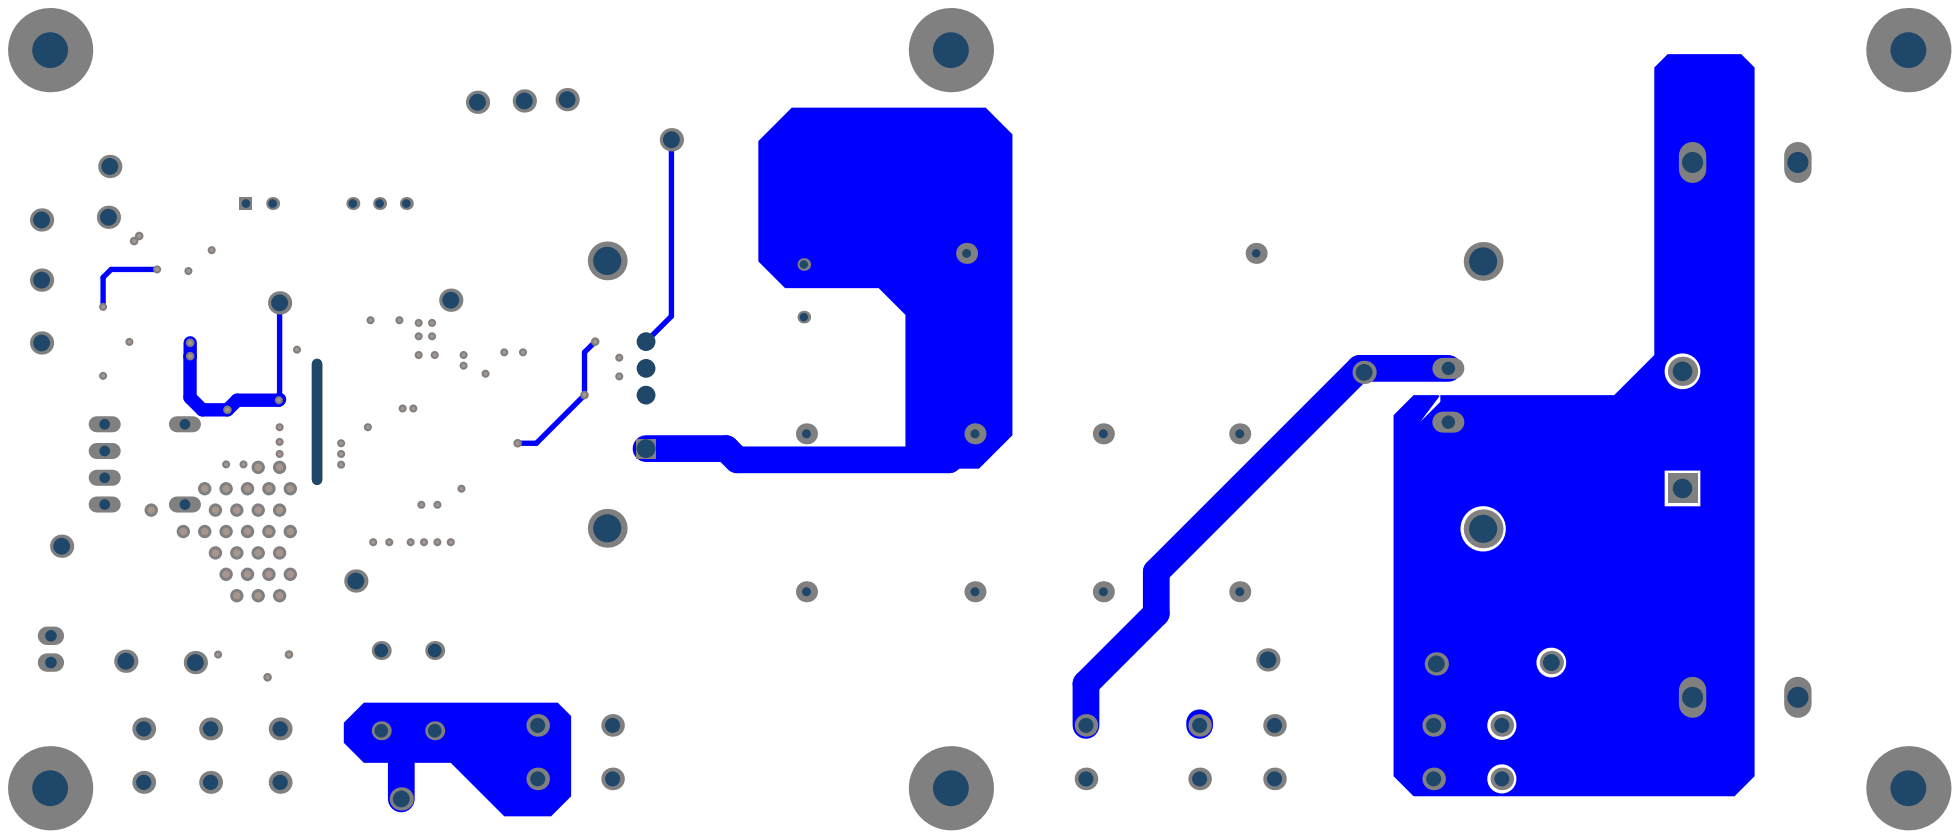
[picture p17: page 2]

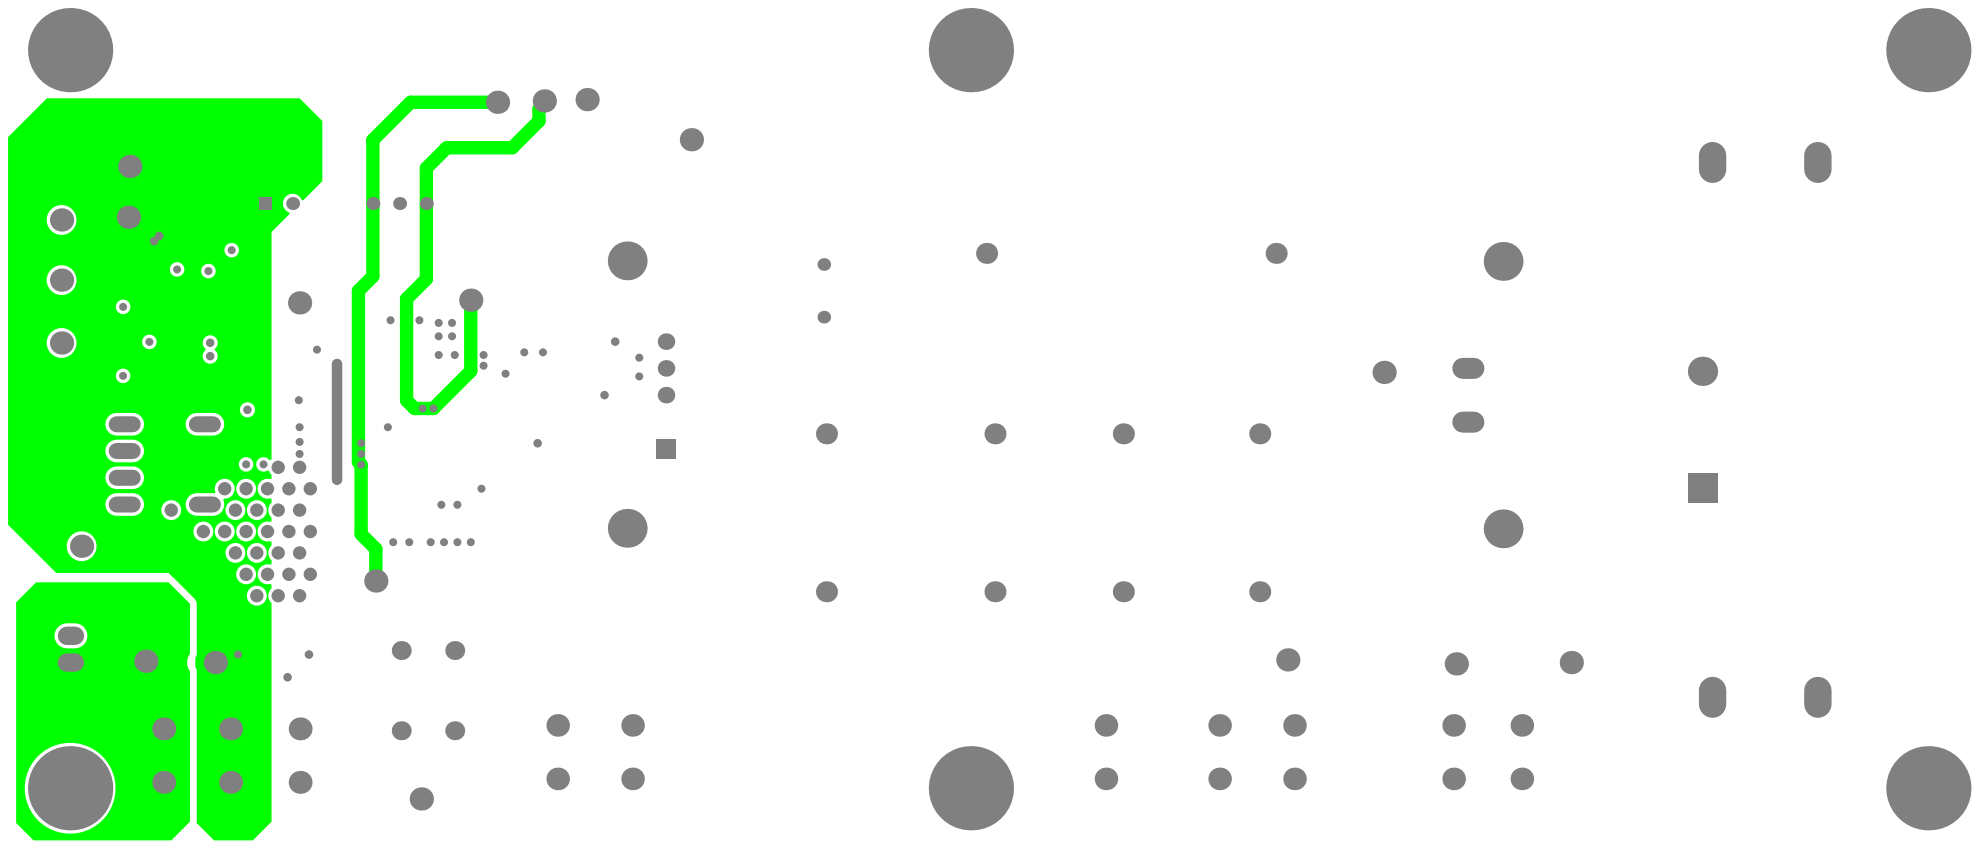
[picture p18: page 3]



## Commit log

2021-03-02 Simulation & PCB files
    [BOM.xlsx, Buck-Boost-Converter.PrjPcb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]
2021-03-03 Add files via upload
    Module of the Buck-Boost PCB
